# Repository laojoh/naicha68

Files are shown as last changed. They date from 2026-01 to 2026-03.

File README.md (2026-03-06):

# naicha68

A keyboard dreamt up and put into solid design by @deltea and @laojoh.

We are both into keyboards, so we wanted to make a keyboard that satisfies both of our wants. Also, keyboards are so cool!
To use our project, you can connect the keyboard through bluetooth to your computer, and type away!

[Check out the Onshape CAD here!](https://cad.onshape.com/documents/295e0b7142940424b9052f56/w/e19706a5ab64c98e31915beb/e/17c8e54cfbba57455b125845)

This keyboard uses the ZMK firmware.

This is the custom layout we chose for the keyboard (made with [keyboard-layout-editor.com](https://www.keyboard-layout-editor.com/#/)):

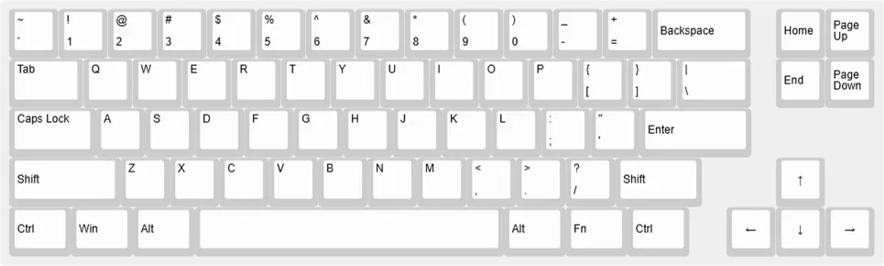
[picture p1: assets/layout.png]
Keyboard Layout


## PCB Renders
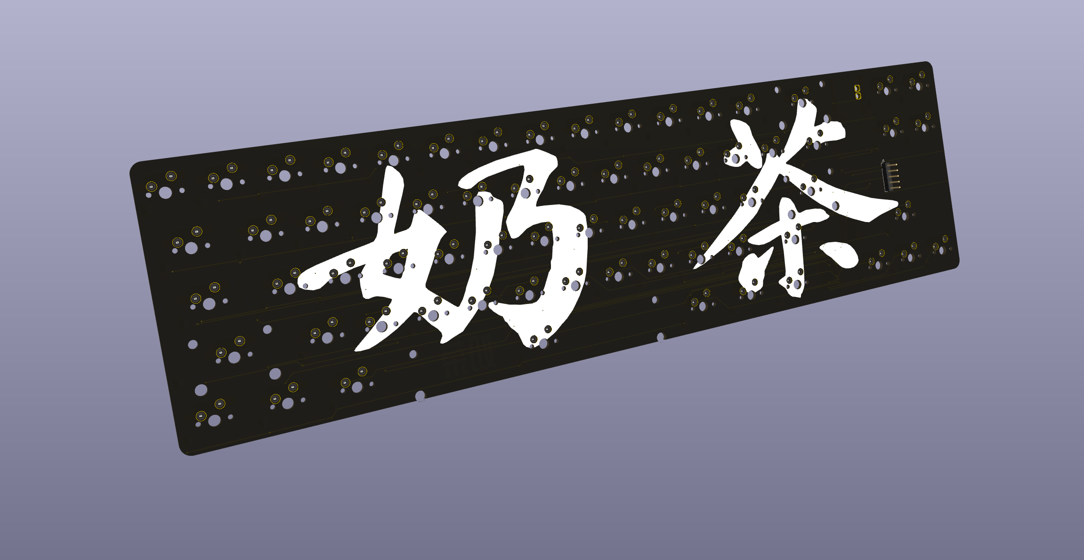
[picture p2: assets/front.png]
Front side

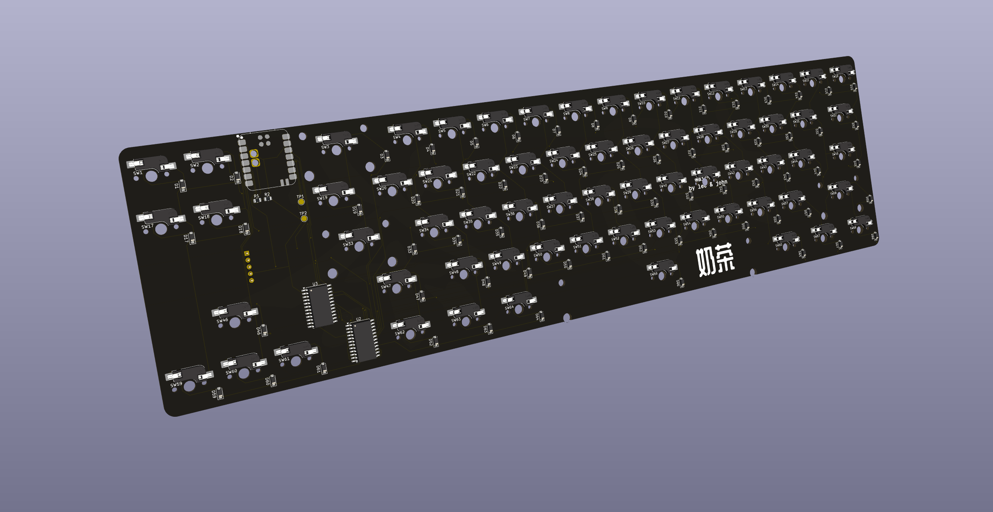
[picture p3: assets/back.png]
Back side


## Case
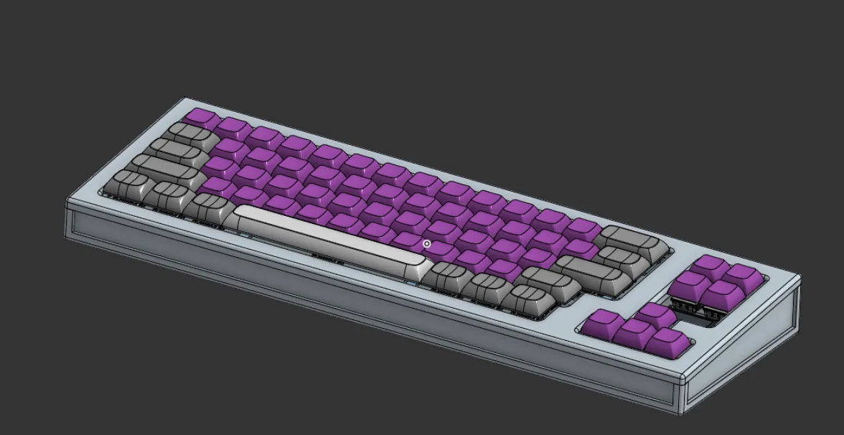
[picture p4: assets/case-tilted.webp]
Tilted View

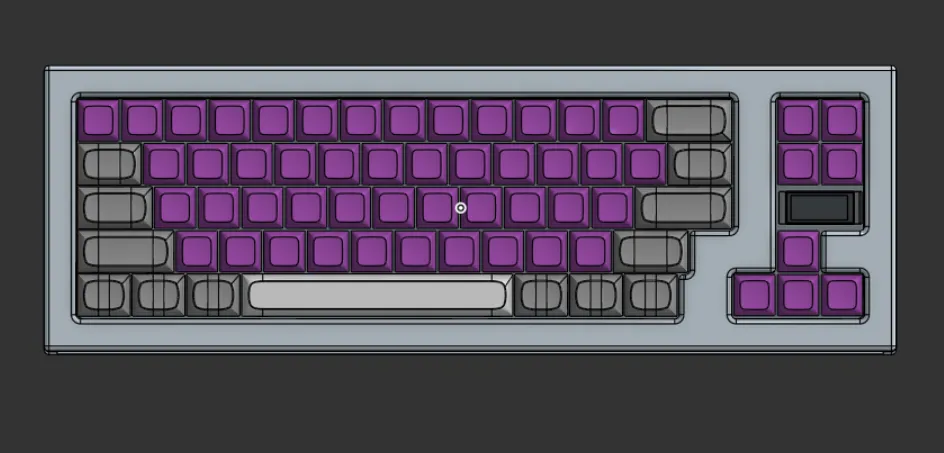
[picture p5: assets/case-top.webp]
Top View


## PCB
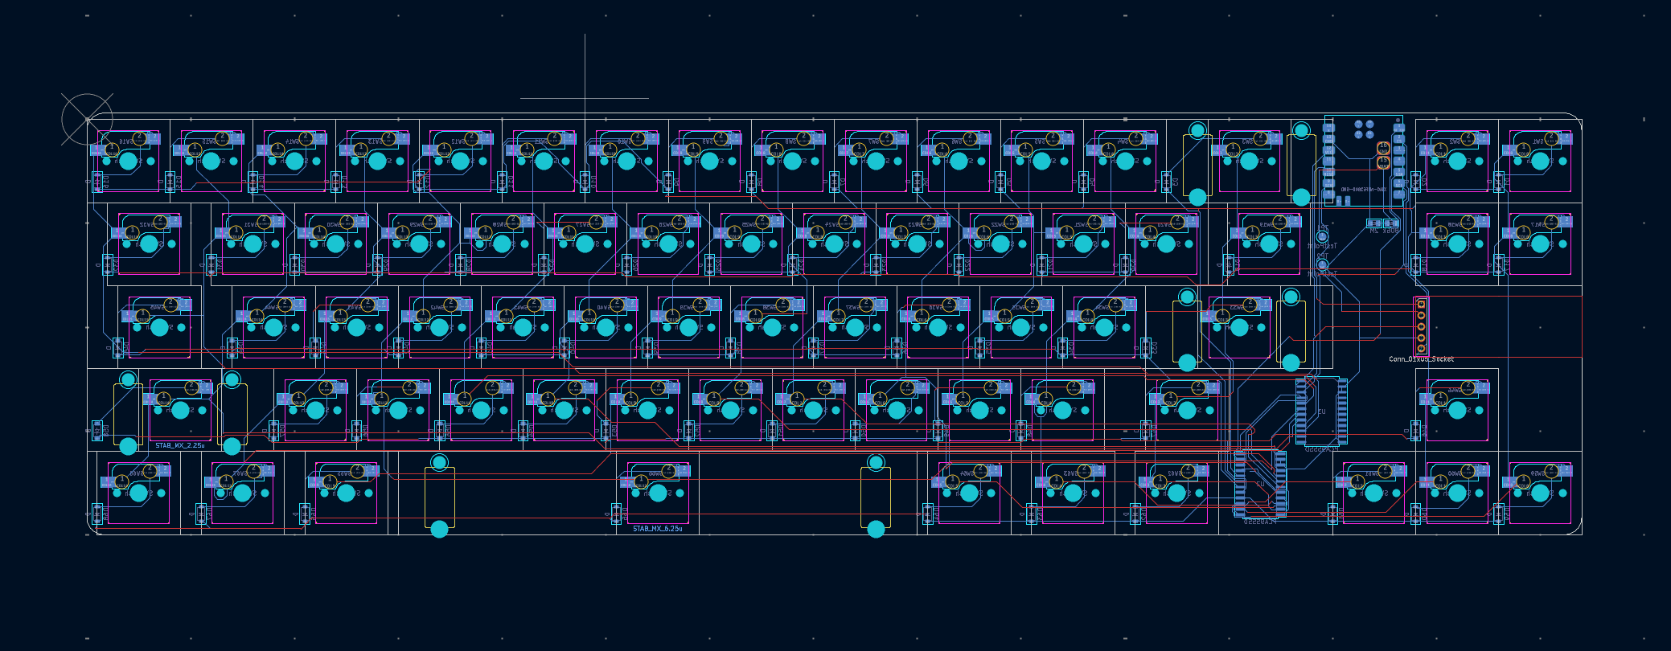
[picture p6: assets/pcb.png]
PCB

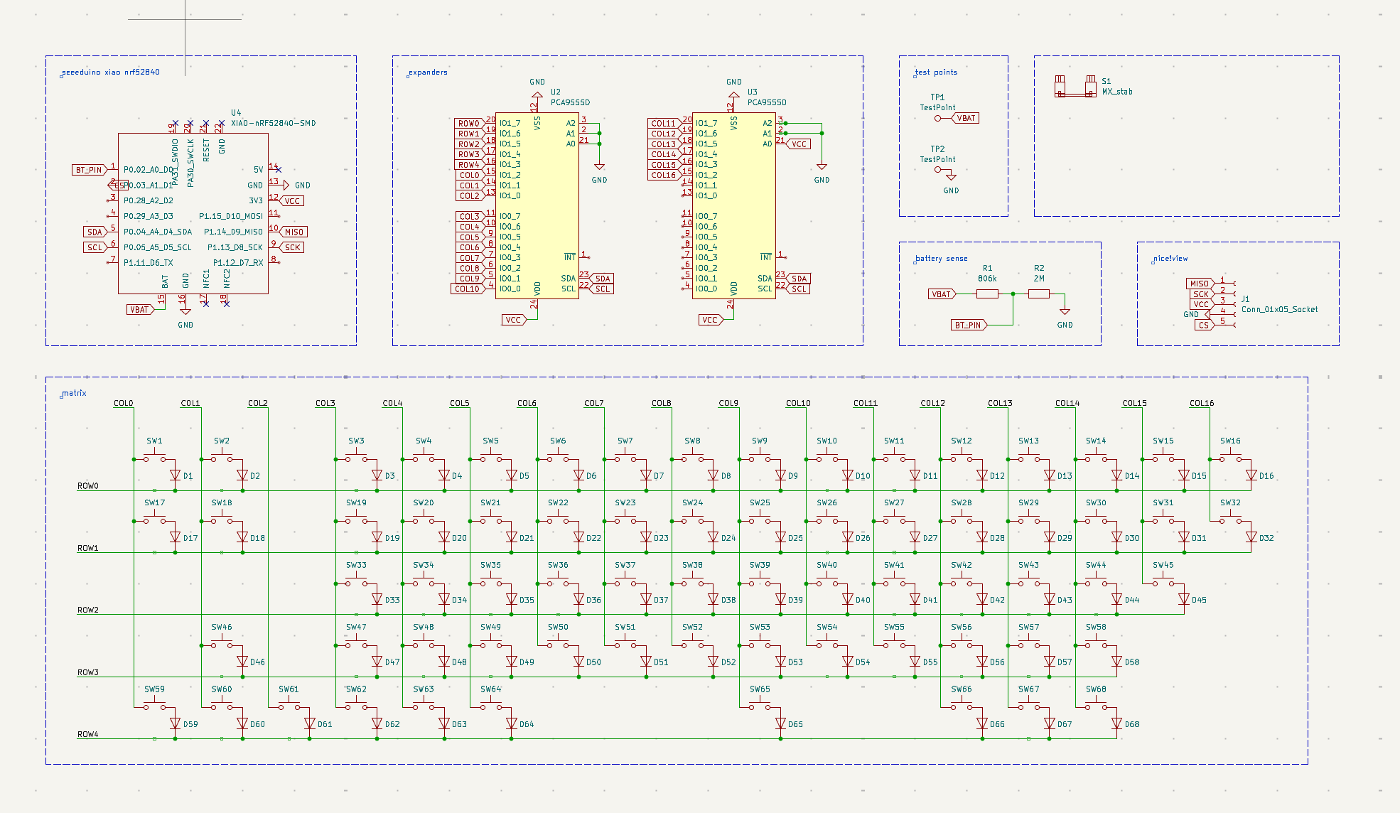
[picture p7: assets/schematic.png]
Schematic


|Name |Quantity|Link/File |Price / unit|Total Price|Stock |Notes|
|---|---|---|---|---|---|-----|
|Totals |10 | | |$177.93 | | |
|Case |1 | |$0.00 |$0.00 |Not yet started| |
|Plate |1 | | |$1.00 |Not yet started| |
|Seeed Studio XIAO nRF52840 |1 |XIAO nRF52840 - Tiny Arduino Board Supports Bluetooth 5.0 |$10.00 |$10.00 |Not yet started| |
|AliExpress Display |1 |https://www.aliexpress.us/item/3256804386173217.html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"order"%3A"1219"%2C"eval"%3A"1"%2C"fromPage"%3A"search"%7D&pdp_npi=6%40dis%21USD%212.10%210.99%21%21%212.10%210.99%21%402103212317701384394338331e3e1c%2112000029674573173%21sea%21US%216679426554%21ABX%211%210%21n_tag%3A-29910%3Bd%3A888201d9%3Bm03_new_user%3A-29895%3BpisId%3A5000000197847477&curPageLogUid=msSzhMdeEBVq&utparam-url=scene%3Asearch%7Cquery_from%3A%7Cx_object_id%3A1005004572487969%7C_p_origin_prod%3A#nav-specification|$7.36 |$7.36 |Not yet started| |
|Kailh Hot-swap PCB Socket Hot Plug for Mechanical Keyboard DIY PCB Accessories (70pcs)|1 |https://www.amazon.com/VEGNRSOT-Hot-swap-Mechanical-Keyboard-Accessories/dp/B0CZ79H1D9?sr=1-2&th=1 |$10.00 |$10.00 |Not yet started| |
|PCB |1 | |$110.58 |$110.58 |Not yet started| |
|Magnets |1 |Amazon.com: 40pcs Small Round Refrigerator Magnets - Mini Craft Magnets for Whiteboard, Dry Erase Board in Home, Kitchen |$6.99 |$6.99 |Not yet started| |
|Gasket Tape |1 |https://www.amazon.com/ToLanbbt-Stripping-Adhesive-Insulation-Weatherproof/dp/B0DSBHMPFT?sr=8-11 |$12.00 |$12.00 |Not yet started| |
|AliExpress Lithium Battery |1 |https://www.aliexpress.us/item/3256809404408618.html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 |$1.00 |$1.00 |Not yet started| |

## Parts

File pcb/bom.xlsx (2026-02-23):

Designator | Footprint | Comment
J2 | JST_JWPF_B02B-JWPF-SK-R_1x02_P2.00mm_Vertical | Conn_01x02_Pin
J1 | PinHeader_1x04_P2.54mm_Vertical | Conn_01x04_Socket
SW43,SW38,SW11,SW65,SW16,SW45,SW57,SW9,SW21,SW59,SW22,SW28,SW34,SW5,SW48,SW53,SW36,SW10,SW41,SW18,SW56,SW33,SW44,SW29,SW62,SW6,SW54,SW13,SW19,SW4,SW31,SW12,SW55,SW32,SW58,SW1,SW68,SW64,SW25,SW24,SW66,SW46,SW27,SW40,SW42,SW14,SW51,SW61,SW30,SW37,SW7,SW47,SW8,SW2,SW35,SW49,SW50,SW60,SW3,SW39,SW23,SW26,SW67,SW15,SW17,SW20,SW63,SW52 | SW_MX_HS_CPG151101S11_1u | SW_Push
D43,D40,D45,D29,D33,D36,D18,D17,D56,D13,D3,D22,D31,D52,D9,D41,D12,D51,D21,D5,D7,D30,D66,D34,D59,D24,D61,D2,D64,D50,D60,D26,D57,D49,D10,D6,D1,D8,D20,D27,D16,D14,D19,D32,D54,D38,D47,D15,D25,D35,D65,D68,D23,D62,D42,D39,D63,D46,D58,D28,D55,D53,D11,D44,D67,D48,D37,D4 | D_SOD-123 | D
U2,U3 | SOIC-24W_7.5x15.4mm_P1.27mm | PCA9555D
R1 | R_0805_2012Metric | 806k
R2 | R_0805_2012Metric | 2M
U4 | modified-XIAO-nRF52840-SMD | XIAO-nRF52840-SMD

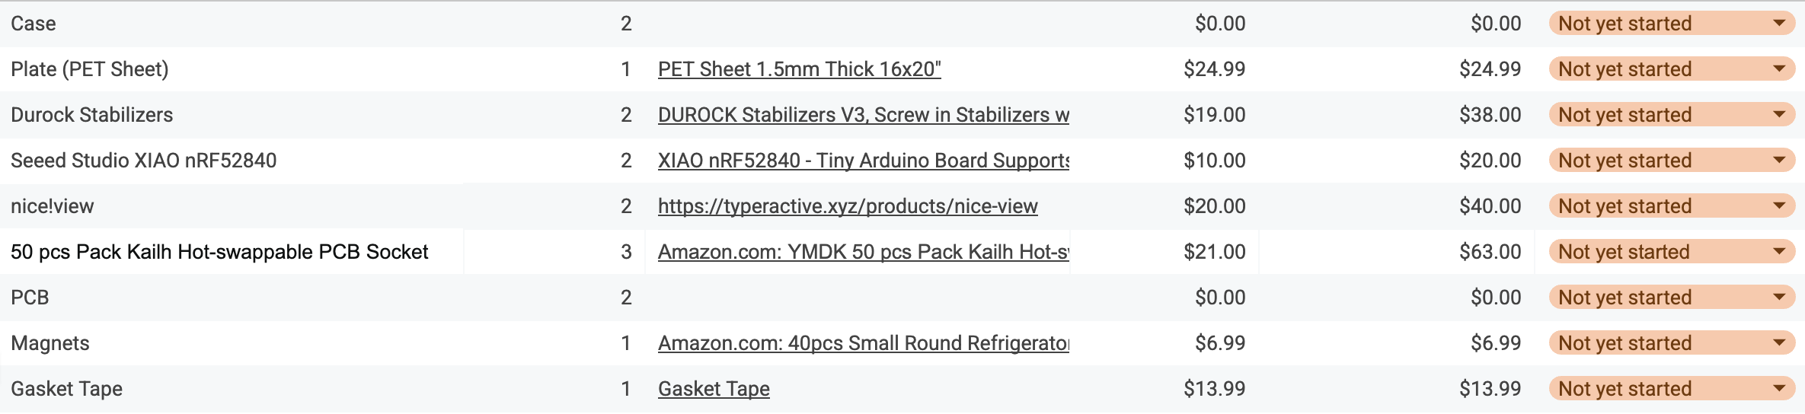
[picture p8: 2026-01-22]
assets/bom.png

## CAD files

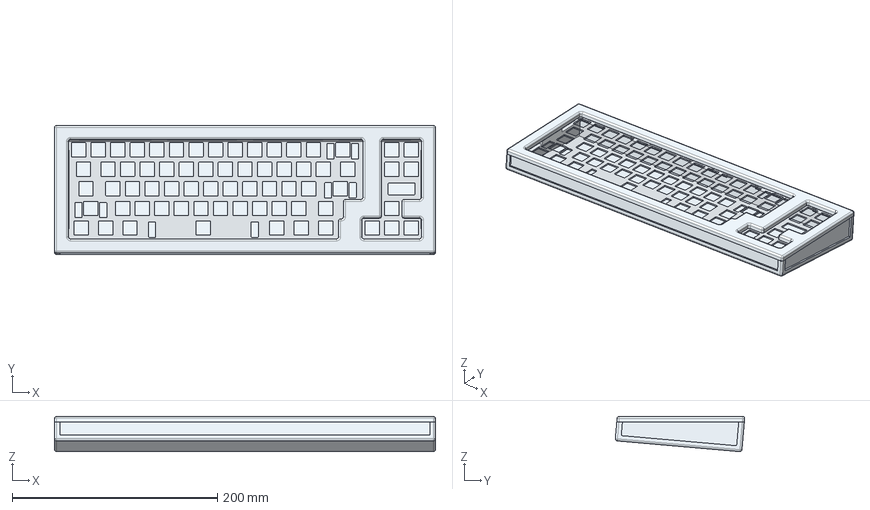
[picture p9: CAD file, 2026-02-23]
step/full.step
370.9 x 126.0 x 34.4 mm
Bottom Case
Top Case
Plate

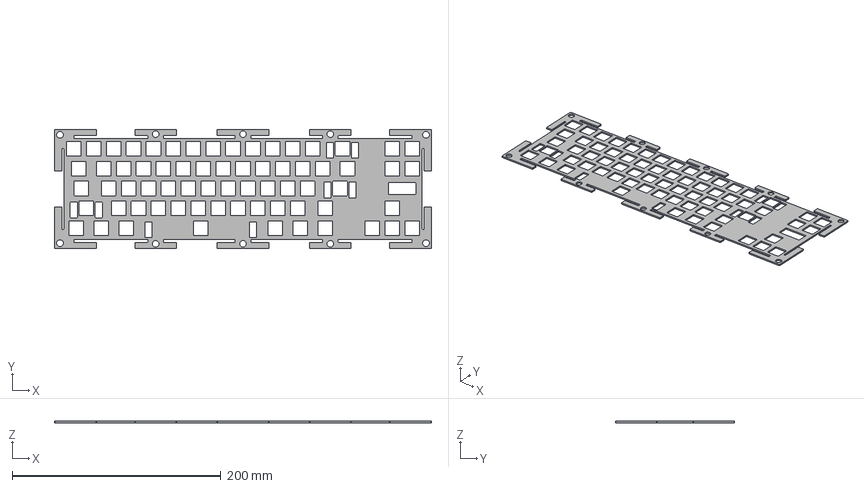
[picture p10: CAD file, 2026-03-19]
STEP files/naicha68 plate.step
360.9 x 114.2 x 1.50 mm

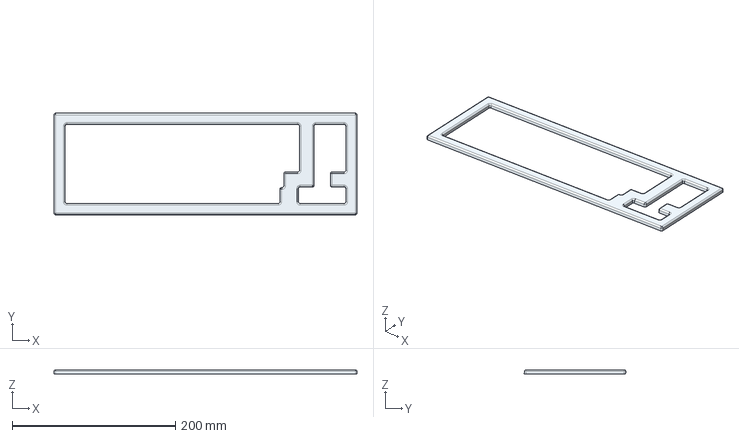
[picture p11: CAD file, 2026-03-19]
step/top-case.step
370.9 x 124.5 x 5.48 mm

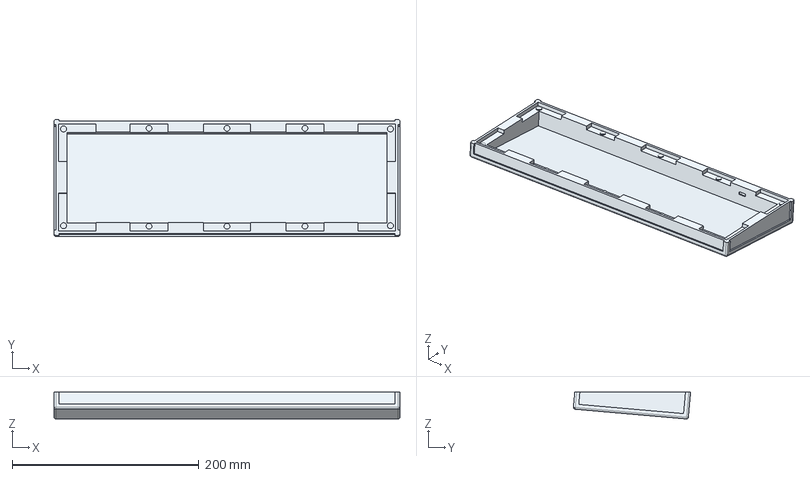
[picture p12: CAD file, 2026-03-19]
step/bottom-case.step
370.9 x 125.7 x 28.9 mm

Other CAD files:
step/plate.step

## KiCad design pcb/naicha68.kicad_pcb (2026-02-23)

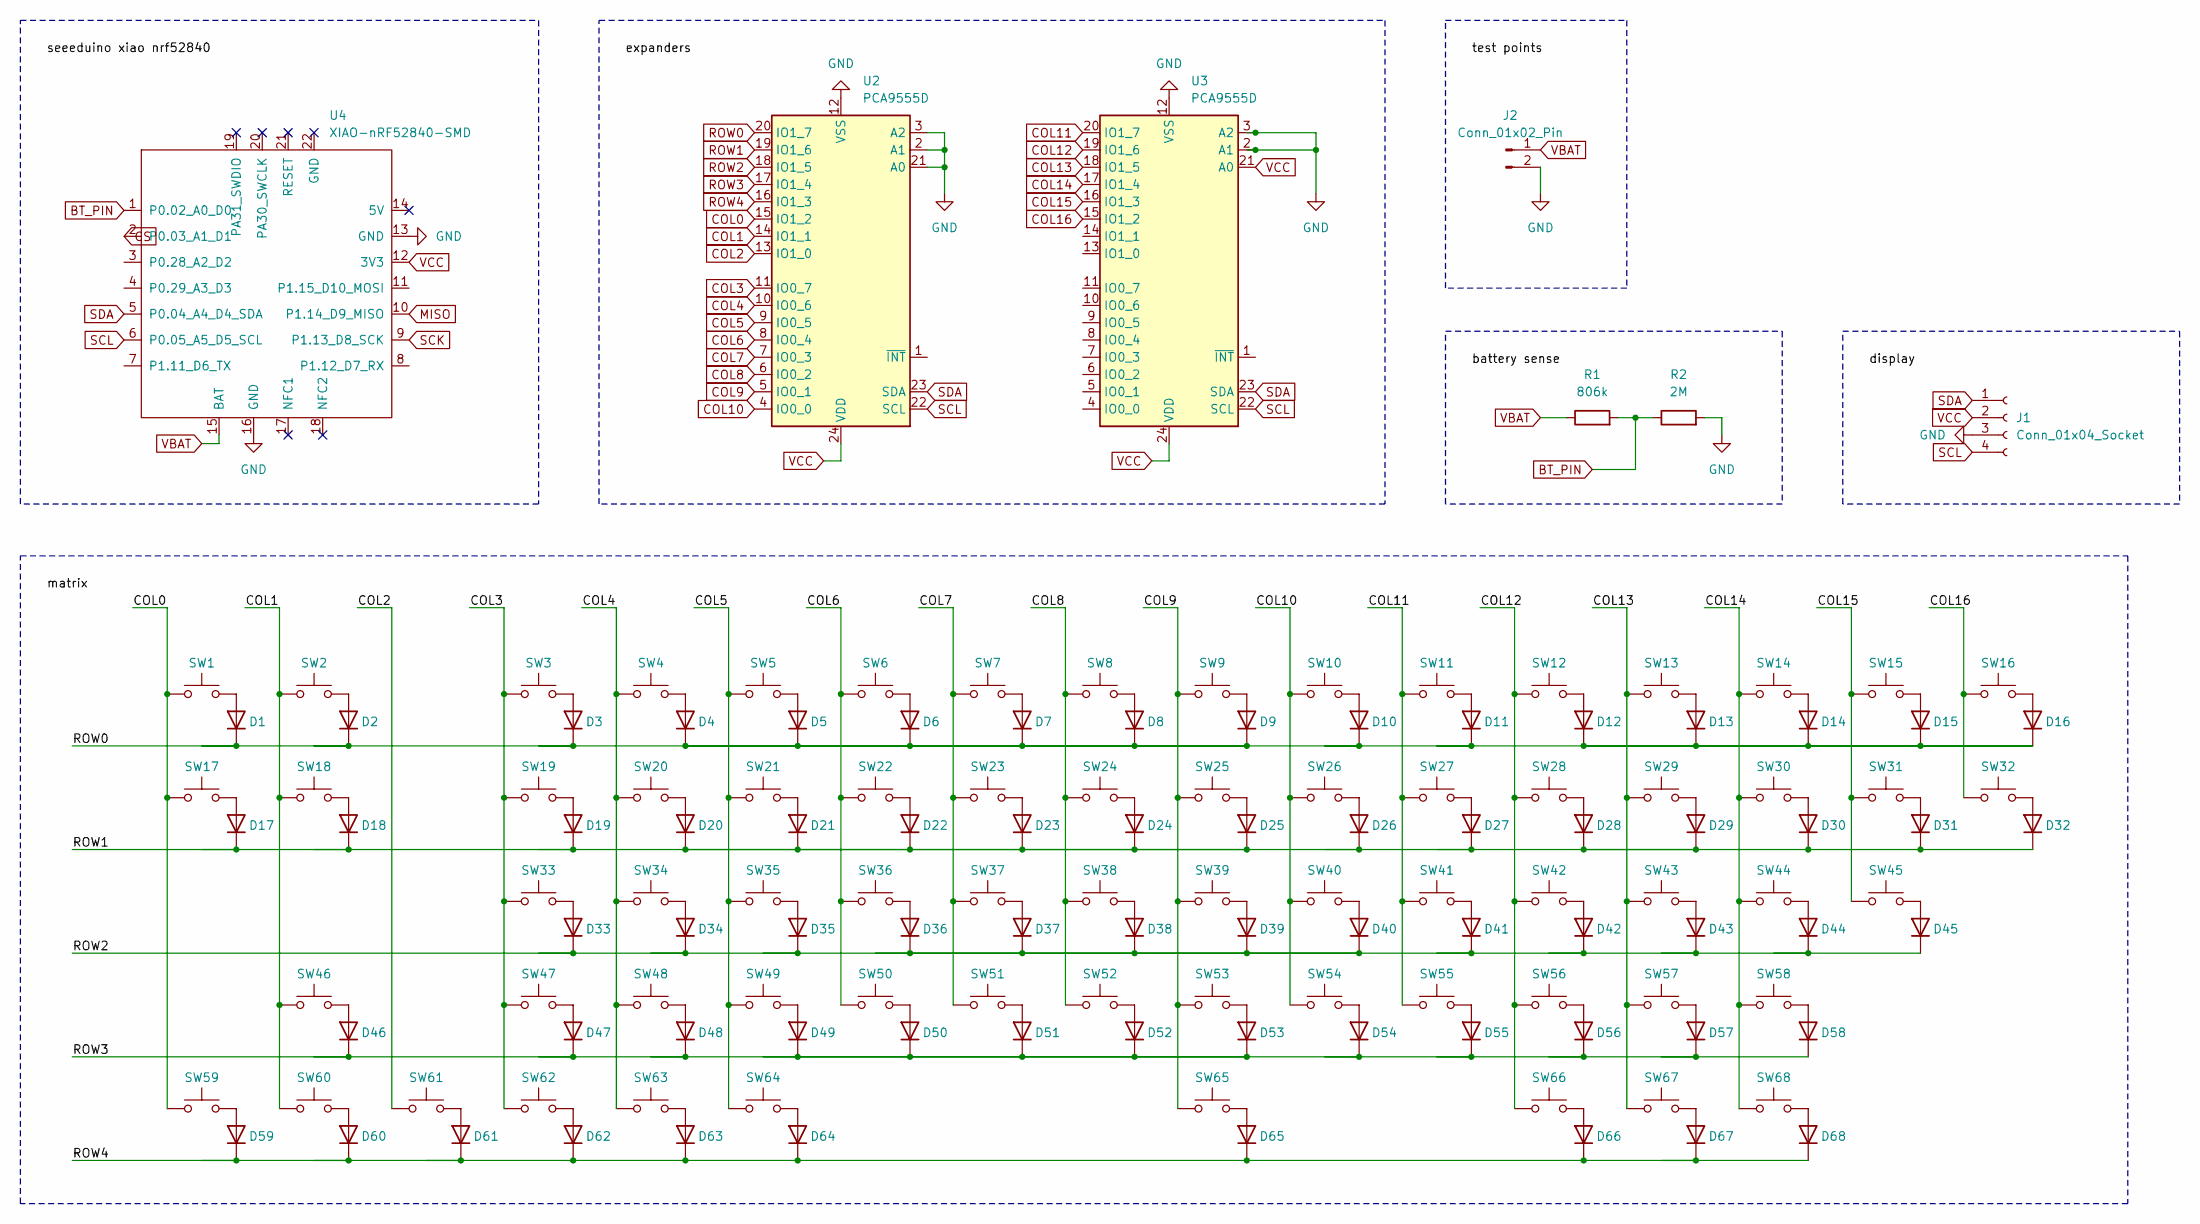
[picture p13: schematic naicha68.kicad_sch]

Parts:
D1, D2, D3, D4, D5, D6, D7, D8, D9, D10, D11, D12, D13, D14, D15, D16, D17, D18, D19, D20, D21, D22, D23, D24, D25, D26, D27, D28, D29, D30, D31, D32, D33, D34, D35, D36, D37, D38, D39, D40, D41, D42, D43, D44, D45, D46, D47, D48, D49, D50, D51, D52, D53, D54, D55, D56, D57, D58, D59, D60, D61, D62, D63, D64, D65, D66, D67, D68: D; D_SOD-123
J1: Conn_01x04_Socket; PinHeader_1x04_P2.54mm_Vertical
J2: Conn_01x02_Pin; JST_JWPF_B02B-JWPF-SK-R_1x02_P2.00mm_Vertical
R1: 806k; R_0805_2012Metric
R2: 2M; R_0805_2012Metric
SW1, SW2, SW3, SW4, SW5, SW6, SW7, SW8, SW9, SW10, SW11, SW12, SW13, SW14, SW15, SW16, SW17, SW18, SW19, SW20, SW21, SW22, SW23, SW24, SW25, SW26, SW27, SW28, SW29, SW30, SW31, SW32, SW33, SW34, SW35, SW36, SW37, SW38, SW39, SW40, SW41, SW42, SW43, SW44, SW45, SW46, SW47, SW48, SW49, SW50, SW51, SW52, SW53, SW54, SW55, SW56, SW57, SW58, SW59, SW60, SW61, SW62, SW63, SW64, SW65, SW66, SW67, SW68: SW_Push; SW_MX_HS_CPG151101S11_1u
U2, U3: PCA9555D; SOIC-24W_7.5x15.4mm_P1.27mm
U4: XIAO-nRF52840-SMD; modified-XIAO-nRF52840-SMD

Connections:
BT_PIN: R1.2, R2.1, U4.1 (P0.02_A0_D0)
COL0: SW1.1, SW17.1, SW59.1, U2.15 (IO1_2)
COL1: SW2.1, SW18.1, SW46.1, SW60.1, U2.14 (IO1_1)
COL2: SW61.1, U2.13 (IO1_0)
COL3: SW3.1, SW19.1, SW33.1, SW47.1, SW62.1, U2.11 (IO0_7)
COL4: SW4.1, SW20.1, SW34.1, SW48.1, SW63.1, U2.10 (IO0_6)
COL5: SW5.1, SW21.1, SW35.1, SW49.1, SW64.1, U2.9 (IO0_5)
COL6: SW6.1, SW22.1, SW36.1, SW50.1, U2.8 (IO0_4)
COL7: SW7.1, SW23.1, SW37.1, SW51.1, U2.7 (IO0_3)
COL8: SW8.1, SW24.1, SW38.1, SW52.1, U2.6 (IO0_2)
COL9: SW9.1, SW25.1, SW39.1, SW53.1, SW65.1, U2.5 (IO0_1)
COL10: SW10.1, SW26.1, SW40.1, SW54.1, U2.4 (IO0_0)
COL11: SW11.1, SW27.1, SW41.1, SW55.1, U3.20 (IO1_7)
COL12: SW12.1, SW28.1, SW42.1, SW56.1, SW66.1, U3.19 (IO1_6)
COL13: SW13.1, SW29.1, SW43.1, SW57.1, SW67.1, U3.18 (IO1_5)
COL14: SW14.1, SW30.1, SW44.1, SW58.1, SW68.1, U3.17 (IO1_4)
COL15: SW15.1, SW31.1, SW45.1, U3.16 (IO1_3)
COL16: SW16.1, SW32.1, U3.15 (IO1_2)
CS: U4.2 (P0.03_A1_D1)
GND: J1.3, J2.2, R2.2, U2.2 (A1), U2.3 (A2), U2.12 (VSS), U2.21 (A0), U3.2 (A1), U3.3 (A2), U3.12 (VSS), U4.13 (GND), U4.16 (GND)
MISO: U4.10 (P1.14_D9_MISO)
unnamed: D1.2 (A), SW1.2
unnamed: D2.2 (A), SW2.2
unnamed: D3.2 (A), SW3.2
unnamed: D4.2 (A), SW4.2
unnamed: D5.2 (A), SW5.2
unnamed: D6.2 (A), SW6.2
unnamed: D7.2 (A), SW7.2
unnamed: D8.2 (A), SW8.2
unnamed: D9.2 (A), SW9.2
unnamed: D10.2 (A), SW10.2
unnamed: D11.2 (A), SW11.2
unnamed: D12.2 (A), SW12.2
unnamed: D13.2 (A), SW13.2
unnamed: D14.2 (A), SW14.2
unnamed: D15.2 (A), SW15.2
unnamed: D16.2 (A), SW16.2
unnamed: D17.2 (A), SW17.2
unnamed: D18.2 (A), SW18.2
unnamed: D19.2 (A), SW19.2
unnamed: D20.2 (A), SW20.2
unnamed: D21.2 (A), SW21.2
unnamed: D22.2 (A), SW22.2
unnamed: D23.2 (A), SW23.2
unnamed: D24.2 (A), SW24.2
unnamed: D25.2 (A), SW25.2
unnamed: D26.2 (A), SW26.2
unnamed: D27.2 (A), SW27.2
unnamed: D28.2 (A), SW28.2
unnamed: D29.2 (A), SW29.2
unnamed: D30.2 (A), SW30.2
unnamed: D31.2 (A), SW31.2
unnamed: D32.2 (A), SW32.2
unnamed: D33.2 (A), SW33.2
unnamed: D34.2 (A), SW34.2
unnamed: D35.2 (A), SW35.2
unnamed: D36.2 (A), SW36.2
unnamed: D37.2 (A), SW37.2
unnamed: D38.2 (A), SW38.2
unnamed: D39.2 (A), SW39.2
unnamed: D40.2 (A), SW40.2
unnamed: D41.2 (A), SW41.2
unnamed: D42.2 (A), SW42.2
unnamed: D43.2 (A), SW43.2
unnamed: D44.2 (A), SW44.2
unnamed: D45.2 (A), SW45.2
unnamed: D46.2 (A), SW46.2
unnamed: D47.2 (A), SW47.2
unnamed: D48.2 (A), SW48.2
unnamed: D49.2 (A), SW49.2
unnamed: D50.2 (A), SW50.2
unnamed: D51.2 (A), SW51.2
unnamed: D52.2 (A), SW52.2
unnamed: D53.2 (A), SW53.2
unnamed: D54.2 (A), SW54.2
unnamed: D55.2 (A), SW55.2
unnamed: D56.2 (A), SW56.2
unnamed: D57.2 (A), SW57.2
unnamed: D58.2 (A), SW58.2
unnamed: D59.2 (A), SW59.2
unnamed: D60.2 (A), SW60.2
unnamed: D61.2 (A), SW61.2
unnamed: D62.2 (A), SW62.2
unnamed: D63.2 (A), SW63.2
unnamed: D64.2 (A), SW64.2
unnamed: D65.2 (A), SW65.2
unnamed: D66.2 (A), SW66.2
unnamed: D67.2 (A), SW67.2
unnamed: D68.2 (A), SW68.2
ROW0: D1.1 (K), D2.1 (K), D3.1 (K), D4.1 (K), D5.1 (K), D6.1 (K), D7.1 (K), D8.1 (K), D9.1 (K), D10.1 (K), D11.1 (K), D12.1 (K), D13.1 (K), D14.1 (K), D15.1 (K), D16.1 (K), U2.20 (IO1_7)
ROW1: D17.1 (K), D18.1 (K), D19.1 (K), D20.1 (K), D21.1 (K), D22.1 (K), D23.1 (K), D24.1 (K), D25.1 (K), D26.1 (K), D27.1 (K), D28.1 (K), D29.1 (K), D30.1 (K), D31.1 (K), D32.1 (K), U2.19 (IO1_6)
ROW2: D33.1 (K), D34.1 (K), D35.1 (K), D36.1 (K), D37.1 (K), D38.1 (K), D39.1 (K), D40.1 (K), D41.1 (K), D42.1 (K), D43.1 (K), D44.1 (K), D45.1 (K), U2.18 (IO1_5)
ROW3: D46.1 (K), D47.1 (K), D48.1 (K), D49.1 (K), D50.1 (K), D51.1 (K), D52.1 (K), D53.1 (K), D54.1 (K), D55.1 (K), D56.1 (K), D57.1 (K), D58.1 (K), U2.17 (IO1_4)
ROW4: D59.1 (K), D60.1 (K), D61.1 (K), D62.1 (K), D63.1 (K), D64.1 (K), D65.1 (K), D66.1 (K), D67.1 (K), D68.1 (K), U2.16 (IO1_3)
SCK: U4.9 (P1.13_D8_SCK)
SCL: J1.4, U2.22 (SCL), U3.22 (SCL), U4.6 (P0.05_A5_D5_SCL)
SDA: J1.1, U2.23 (SDA), U3.23 (SDA), U4.5 (P0.04_A4_D4_SDA)
VBAT: J2.1, R1.1, U4.15 (BAT)
VCC: J1.2, U2.24 (VDD), U3.21 (A0), U3.24 (VDD), U4.12 (3V3)

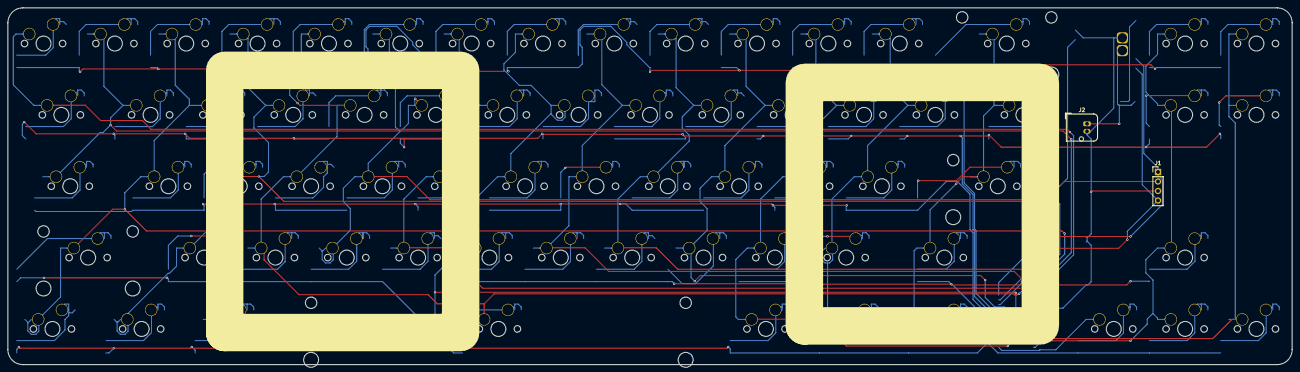
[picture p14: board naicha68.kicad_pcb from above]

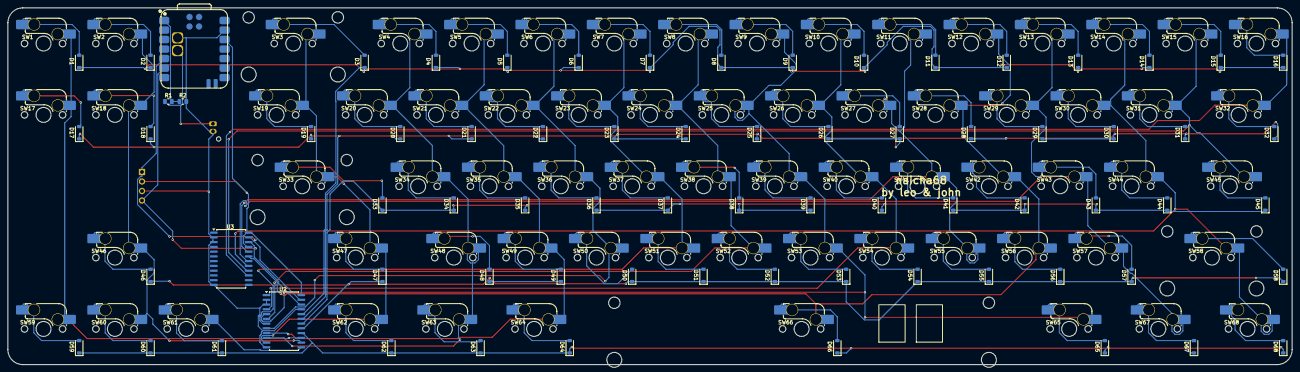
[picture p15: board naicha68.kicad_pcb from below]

Board: 2 copper layers, 342.9 x 95.2 mm, 147 parts (141 on the bottom side), 96 nets.

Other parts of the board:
S1: STAB_MX_2u
S2, S3: STAB_MX_2.25u
S4: STAB_MX_6.25u

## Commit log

2026-01-22 upload bom
    [bom.csv]
2026-01-22 upload kicad_pro file
2026-01-22 add bom to readme
2026-01-29 update readme with bom table and description
2026-01-29 new pcb upload
    [bom.csv, naicha68.kicad_pcb]
2026-02-04 new pcb udpates
    [naicha68.kicad_pcb, naicha68.kicad_sch]
2026-02-23 Include CAD link in README
    Added a link to the CAD document for the keyboard project.
2026-02-23 added STEP file
    [奶茶68.step]
2026-02-23 add new kicad files
    [bom.xlsx, naicha68.kicad_pcb, pick-and-place.xlsx]
2026-02-23 update bom
2026-03-06 add screenshots of case cad
2026-03-20 organize folders and files
    [bottom-case.step, full.step, plate.step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]
